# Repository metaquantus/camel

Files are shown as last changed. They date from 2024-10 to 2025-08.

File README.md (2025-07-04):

# Camel I2C Dual HX712 Weigh Scales Board

Camel is a board with Dual HX712 Weigh Scales ADCs controlled by a low power STM32L010F4 or STM32L031F6 MCU providing an I2C slave interface.
Power is provided by an I2C Adafruit STEMMA compatible 4-pin JST PH (2mm pitch) connector. This board will work 
with power from 3.3V to 5V, but it's better if VCC > 4V. 

It was intended to support the integrated scales mod for the Gaggia Classic Pro espresso machine provided by the Gaggiuino project. But instead of the main MCU driving the HX712s directly, sensor reading and decoding is offloaded to this board's MCU and a simple I2C interface is used instead to connect to the host MCU. This reduces the number of wires required, frees some pins in the host MCU and saves some clock cycles.

STEMMA Pinouts:
```
1 Green for SCL
2 White for SDA
3 Red for VCC+
4 Black for GND
```

The MCU drives the 2 HX712 ADCs, reads and decodes the conversions and provides the raw data to the host via I2C. 
The HX712s allow programmatic configuration of the sampling rate (10Hz or 40Hz), the amplifier's gain
factor (128 or 256) and whether to put the HX712s into power down mode consuming less than 1uA.
The device can also store configuration and calibration points in the MCU's EEPROM. Up to 4 calibration points 
are supported. 
The host is in charge of providing additional functions like scaling to weight units, tare and calibration.
It may be possible to offload scaling to the MCU, if using STM32L031F6 as it has more memory.
I2C doesn't support slave initiated transfers so the host MCU must poll the device periodically to read the data.
There will be roughly one new sensor reading available of both load cells every 100ms if 10Hz sampling rate is used. 
The internal oscillator is used in both the HX712 ADCs and the MCU so sampling rates are not very precise.
Using the lower sampling rate has lower conversion noise. The HX712 is a 24-bit ADC and data is provided in 2's complement format.
Readings could be negative depending on how the load cell is mechanically setup, bending one way of the other.
For example, in some of the integrated scales mod assembles, one cell gives positive values and 
the other negative. To get the total weight reading, the absolute values of both cells should be added.

According to STM32CubeIDE, the MCU should consume about 5mA and the HX712s about 1mA each. 

If using only one of the HX712s, it's possible power down the other, saving 1mA. This can be configured from
the host.

Programming is done via a Serial Wire Debug (SWD) connector. Both a Tag-Connect TC2030-NL and a 4-pin 2.54mm pitch header are provided for SWD.

A USART connector is provided but the STM32L010F4 has only 16Kb flash/2Kb RAM and adding code support exceeds code size limit. Some reporting
was tried but code size was very tight. This was intended for monitor and debugging during development, so it's not essential. Maybe with the
STM32L031F6 with 32KB flash/8KB RAM more monitoring and functions like standalone calibration can be added.

ESD protection diodes were added to the interface connectors.

2.54mm pitch header THT pads are used for the load cell connectors, but normally the load cells wires should be soldered directly to the pads instead of using headers or other connector.

## PCB Notes

The variable FAB\_ON\_PLACEHOLDER should be set to JLCJLCJLCJLC, WayWayWay or whatever string is specified by the Fab to position the order number.
Or removed altogether if so desired. Sometimes a fee is incurred if removed.

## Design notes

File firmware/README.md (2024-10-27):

# Camel Weigh Scales Board Firmware

This MCU only has 16KB flash storage and 2KB RAM, so we're pretty tight.
In fact it doesn't fit in Debug mode.
In Release mode it takes about 10KB.
No space for USART code, maybe if we don't use the HAL libraries,
we can squeze some basic code for the USART, though not needed if the main
functions of reading the HX711 and providing the I2C driver are supported.

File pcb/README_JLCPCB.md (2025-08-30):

# JLCPCB Procedure

## Gerbers

### Layers:
 * F.Cu
 * B.Cu
 * F.Paste
 * B.Paste
 * F.Silkscreen
 * B.Silkscreen
 * F.Mask
 * B.Mask
 * Edge.Cuts - (contain the board outline/cutouts.)
 * In1.Cu, In2.Cu … - (needed for 4/6 layer designs.)
 
### Options
 * Select Plot reference designators, otherwise designators will not appear on silkscreen layers;
 * Select Plot footprint text;
 * Select Check zone fills before plotting;
 * Select Tent vias;
 * Select Use Protel filename extensions, this is recommended as JLCPCB prefers Protel filename extensions;
 * Select Subtract soldermask from silkscreen, this ensures no silkscreen on pads;

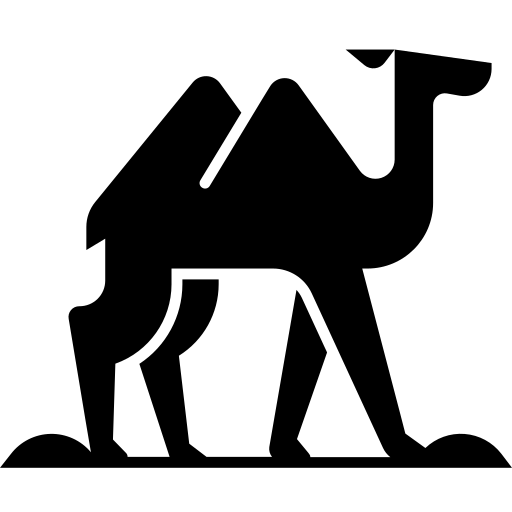
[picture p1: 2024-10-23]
other/camel1.png

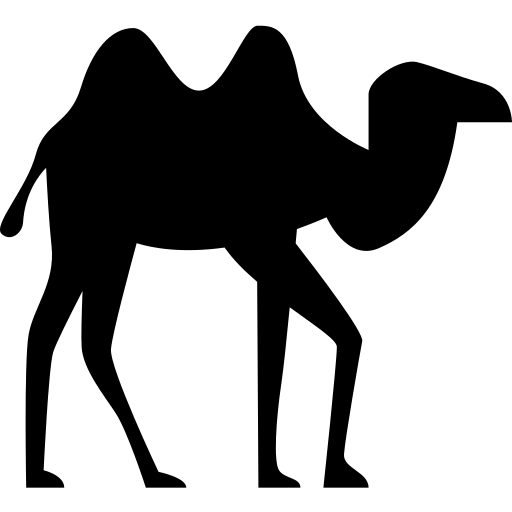
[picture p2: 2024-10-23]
other/camel2.png

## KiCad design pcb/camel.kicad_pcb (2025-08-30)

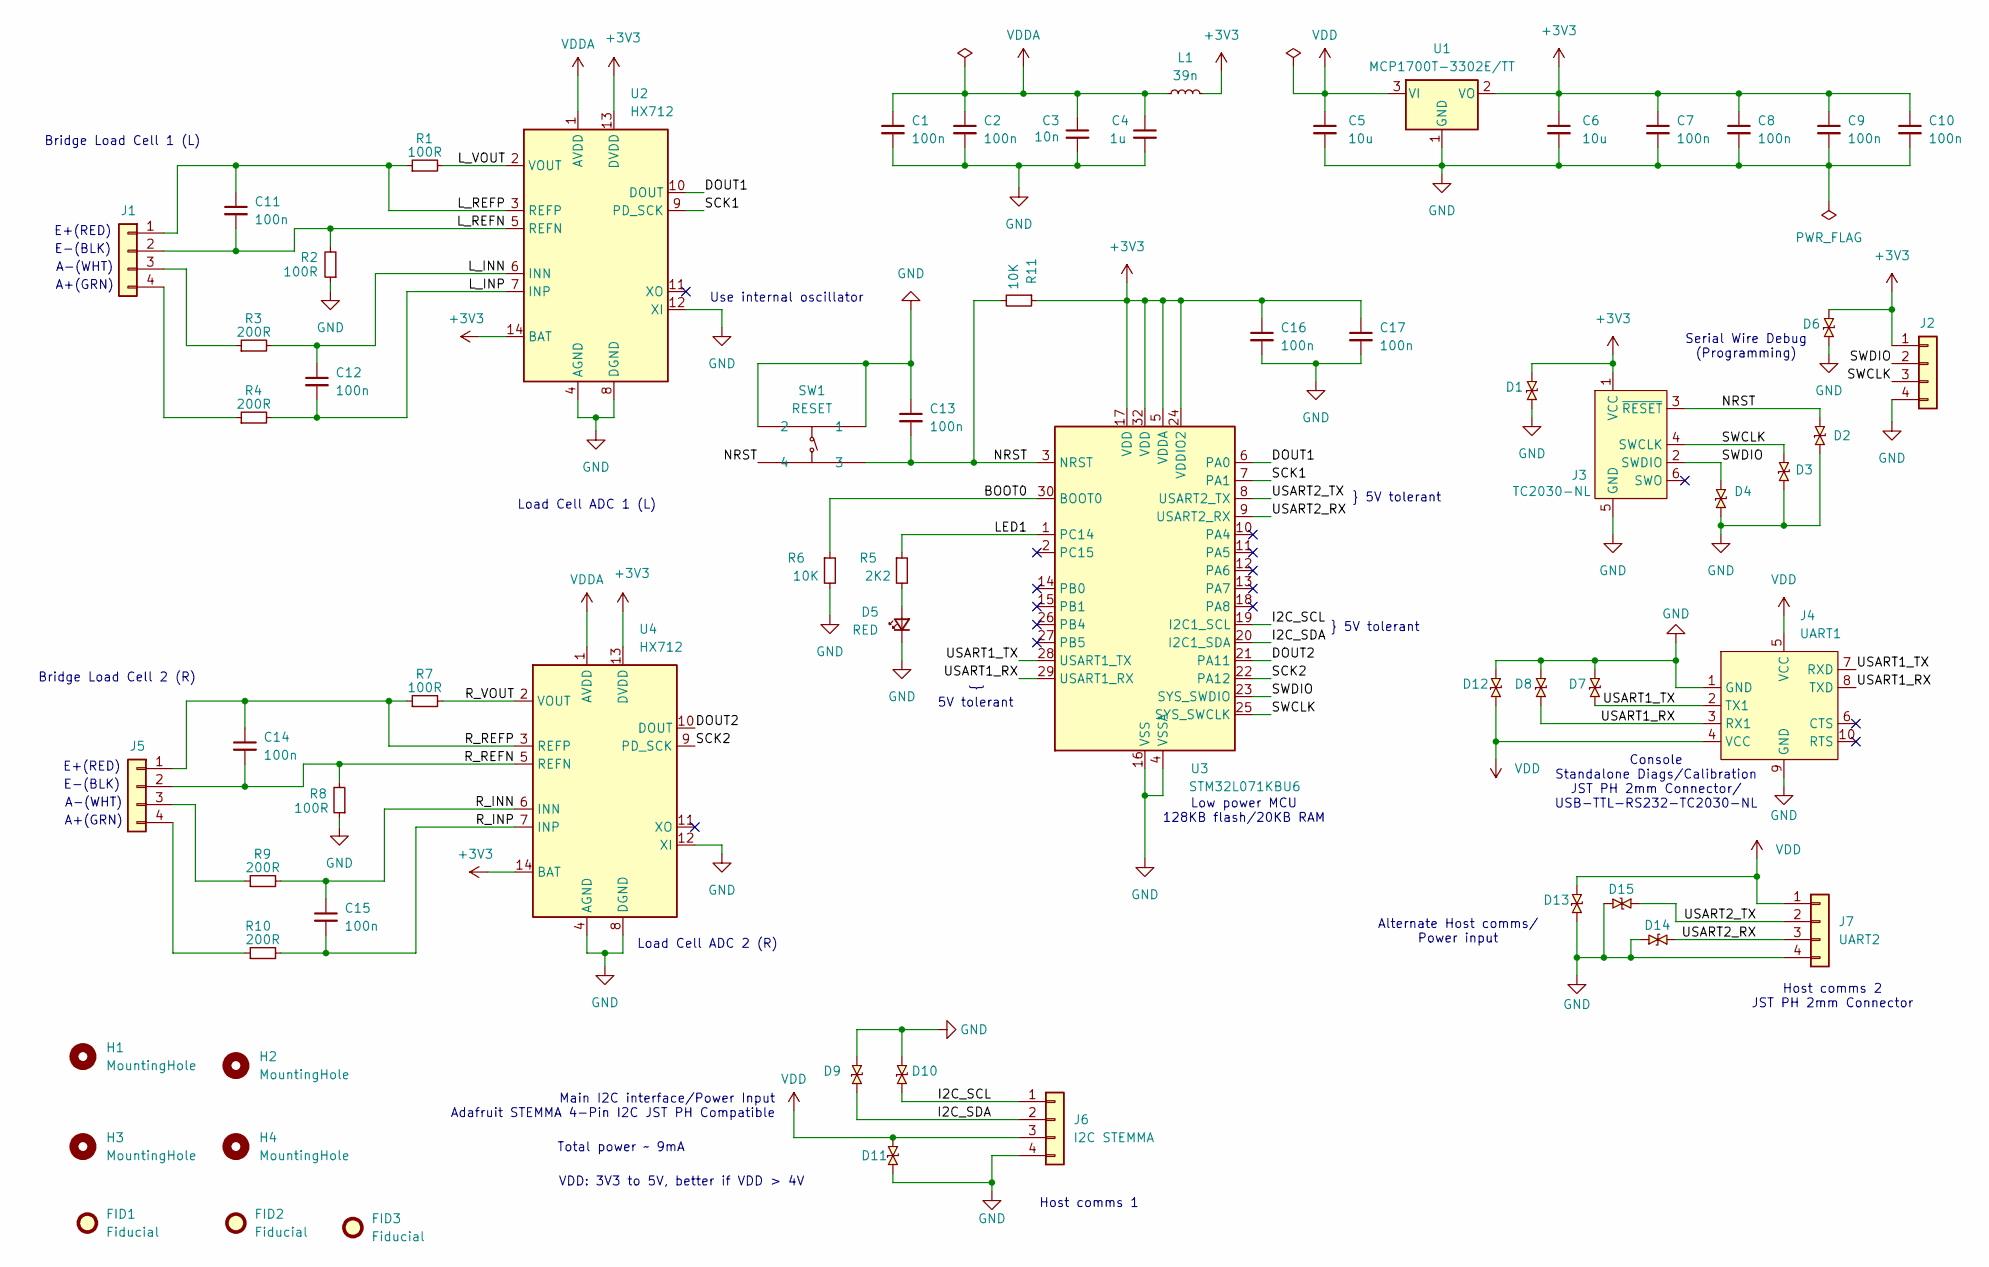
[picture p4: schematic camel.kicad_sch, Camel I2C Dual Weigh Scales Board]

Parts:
C1, C2, C7, C8, C9, C10, C11, C12, C13, C14, C15, C16, C17: 100n; C_0402_1005Metric; LCSC C1525
C3: 10n; C_0402_1005Metric; LCSC C15195
C4: 1u; C_0402_1005Metric; LCSC C29266
C5, C6: 10u; C_0603_1608Metric; LCSC C96446
D1, D2, D3, D4, D6, D7, D8, D9, D10, D11, D12, D13, D14, D15: RCLAMP0521P-N; X1-DFN1006-2_L1.0-W0.6-BI; LCSC C316043
D5: RED; LED_0603_1608Metric; LCSC C2286
FID1, FID2, FID3: Fiducial; Fiducial_0.5mm_Mask1mm
H1, H2, H3, H4: MountingHole; MountingHole_3.2mm_M3
J1, J2, J5: Conn_01x04; Pad_1x04_P2.54mm
J3: TC2030-NL; Tag-Connect_TC2030-IDC-NL_2x03_P1.27mm_Vertical
J4: UART1; JST_PH_S4B-PH-K_1x04_P2.00mm_Horizontal_TC-2030-IDC-NL_2x03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
J6: I2C STEMMA; JST_PH_S4B-PH-K_1x04_P2.00mm_Horizontal; LCSC C265452
J7: UART2; JST_PH_S4B-PH-K_1x04_P2.00mm_Horizontal
L1: 39n; L_1008_2520Metric; LCSC C346422
R1, R2, R7, R8: 100R; R_0402_1005Metric; LCSC C328416
R3, R4, R9, R10: 200R; R_0402_1005Metric; LCSC C413070
R5: 2K2; R_0402_1005Metric; LCSC C25879
R6, R11: 10K; R_0402_1005Metric; LCSC C317926
SW1: RESET; SW-SMD_4P-L3.0-W2.6-P1.80-LS3.5; LCSC Part C390663
U1: MCP1700T-3302E/TT; SOT-23; LCSC C39051
U2, U4: HX712; SOIC-14_3.9x8.7mm_P1.27mm; LCSC C118237
U3: STM32L071KBU6; QFN-32-1EP_5x5mm_P0.5mm_EP3.45x3.45mm; LCSC C911078

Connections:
+3V3: C6.1, C7.1, C8.1, C9.1, C10.1, C16.1, C17.1, D1.1, D6.1, J2.1, J3.1 (VCC), L1.2, R11.1, U1.2 (VO), U2.13 (DVDD), U2.14 (BAT), U3.5 (VDDA), U3.17 (VDD), U3.24 (VDDIO2), U3.32 (VDD), U4.13 (DVDD), U4.14 (BAT)
/BOOT0: R6.1, U3.30 (BOOT0)
/DOUT1: U2.10 (DOUT), U3.6 (PA0)
/DOUT2: U3.21 (PA11), U4.10 (DOUT)
/I2C_SCL: D10.2, J6.1, U3.19 (I2C1_SCL)
/I2C_SDA: D9.2, J6.2, U3.20 (I2C1_SDA)
/LED1: R5.1, U3.1 (PC14)
/L_INN: C12.1, R3.2, U2.6 (INN)
/L_INP: C12.2, R4.2, U2.7 (INP)
/L_REFN: C11.2, J1.2, R2.2, U2.5 (REFN)
/L_REFP: C11.1, J1.1, R1.1, U2.3 (REFP)
/L_VOUT: R1.2, U2.2 (VOUT)
/NRST: C13.2, D2.1, J3.3 (~RESET), R11.2, SW1.3, SW1.4, U3.3 (NRST)
/R_INN: C15.1, R9.2, U4.6 (INN)
/R_INP: C15.2, R10.2, U4.7 (INP)
/R_REFN: C14.2, J5.2, R8.2, U4.5 (REFN)
/R_REFP: C14.1, J5.1, R7.1, U4.3 (REFP)
/R_VOUT: R7.2, U4.2 (VOUT)
/SCK1: U2.9 (PD_SCK), U3.7 (PA1)
/SCK2: U3.22 (PA12), U4.9 (PD_SCK)
/SWCLK: D3.1, J2.3, J3.4 (SWCLK), U3.25 (SYS_SWCLK)
/SWDIO: D4.1, J2.2, J3.2 (SWDIO), U3.23 (SYS_SWDIO)
/USART1_RX: D8.2, J4.3 (RX1), J4.8 (TXD), U3.29 (USART1_RX)
/USART1_TX: D7.2, J4.2 (TX1), J4.7 (RXD), U3.28 (USART1_TX)
/USART2_RX: D14.2, J7.3, U3.9 (USART2_RX)
/USART2_TX: D15.2, J7.2, U3.8 (USART2_TX)
GND: C1.2, C2.2, C3.2, C4.2, C5.2, C6.2, C7.2, C8.2, C9.2, C10.2, C13.1, C16.2, C17.2, D1.2, D2.2, D3.2, D4.2, D5.1 (K), D6.2, D7.1, D8.1, D9.1, D10.1, D11.2, D12.1, D13.2, D14.1, D15.1, J2.4, J3.5 (GND), J4.1 (GND), J4.9 (GND), J6.4, J7.4, R2.1, R6.2, R8.1, SW1.1, SW1.2, U1.1 (GND), U2.4 (AGND), U2.8 (DGND), U2.12 (XI), U3.4 (VSSA), U3.16 (VSS), U3.31 (VSS), U3.33 (VSS), U4.4 (AGND), U4.8 (DGND), U4.12 (XI)
unnamed: D5.2 (A), R5.2
unnamed: J1.3, R3.1
unnamed: J1.4, R4.1
unnamed: J5.3, R9.1
unnamed: J5.4, R10.1
VDD: C5.1, D11.1, D12.2, D13.1, J4.4 (VCC), J4.5 (VCC), J6.3, J7.1, U1.3 (VI)
VDDA: C1.1, C2.1, C3.1, C4.1, L1.1, U2.1 (AVDD), U4.1 (AVDD)

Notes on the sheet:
A-(WHT)
Bridge Load Cell 2 (R)
5V tolerant
Alternate Host comms/ Power input
Load Cell ADC 2 (R)
Host comms 2 JST PH 2mm Connector
Host comms 1
VDD: 3V3 to 5V, better if VDD > 4V
Console Standalone Diags/Calibration JST PH 2mm Connector/ USB-TTL-RS232-TC2030-NL
E+(RED)
Main I2C interface/Power Input Adafruit STEMMA 4-Pin I2C JST PH Compatible
Total power ~ 9mA
A+(GRN)
Low power MCU 128KB flash/20KB RAM
E-(BLK)
Load Cell ADC 1 (L)
Serial Wire Debug (Programming)
} 5V tolerant
Use internal oscillator
Bridge Load Cell 1 (L)

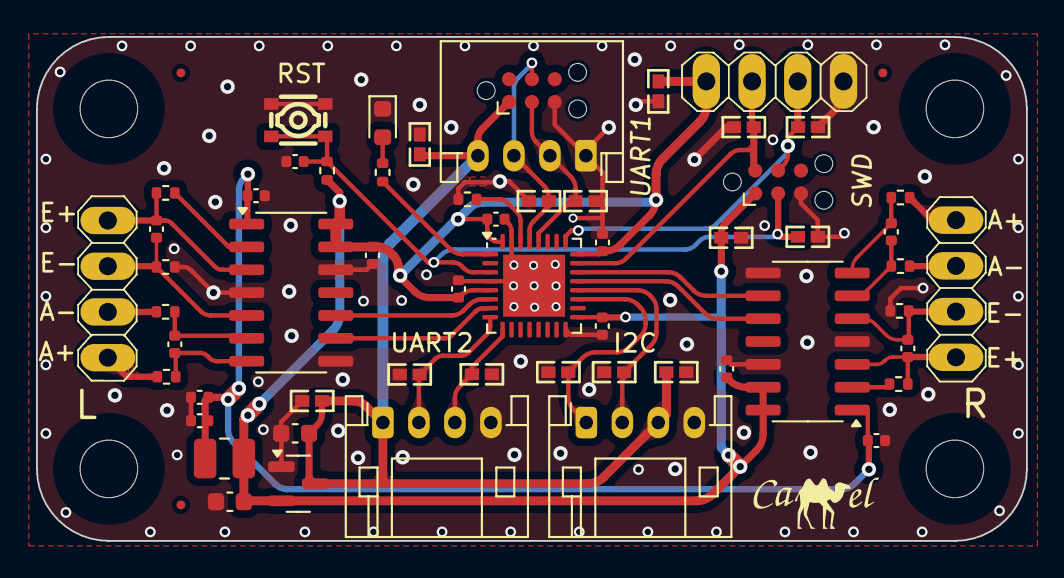
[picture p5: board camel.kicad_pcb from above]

Board: 4 copper layers, 55.0 x 28.0 mm, 65 parts (1 on the bottom side), 34 nets.

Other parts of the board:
G3: LOGO; camel_logo_7
QR1: QR; camel_qrcode_5x5

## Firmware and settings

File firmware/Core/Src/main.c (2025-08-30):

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
/* Includes ------------------------------------------------------------------*/
#include "main.h"
#include "cmsis_os.h"

CRC_HandleTypeDef hcrc;

I2C_HandleTypeDef hi2c1;

UART_HandleTypeDef huart1;
UART_HandleTypeDef huart2;
DMA_HandleTypeDef hdma_usart1_tx;
DMA_HandleTypeDef hdma_usart1_rx;
DMA_HandleTypeDef hdma_usart2_tx;
DMA_HandleTypeDef hdma_usart2_rx;

/* Definitions for defaultTask */
osThreadId_t defaultTaskHandle;
const osThreadAttr_t defaultTask_attributes = {
  .name = "defaultTask",
  .stack_size = 128 * 4,
  .priority = (osPriority_t) osPriorityNormal,
};
/* Definitions for consoleTask */
osThreadId_t consoleTaskHandle;
const osThreadAttr_t consoleTask_attributes = {
  .name = "consoleTask",
  .stack_size = 320 * 4,
  .priority = (osPriority_t) osPriorityLow7,
};
/* Definitions for hostCommTask */
osThreadId_t hostCommTaskHandle;
const osThreadAttr_t hostCommTask_attributes = {
  .name = "hostCommTask",
  .stack_size = 128 * 4,
  .priority = (osPriority_t) osPriorityBelowNormal,
};
/* Definitions for indicatorTask */
osThreadId_t indicatorTaskHandle;
const osThreadAttr_t indicatorTask_attributes = {
  .name = "indicatorTask",
  .stack_size = 192 * 4,
  .priority = (osPriority_t) osPriorityLow,
};
void SystemClock_Config(void);
static void MX_GPIO_Init(void);
static void MX_DMA_Init(void);
static void MX_I2C1_Init(void);
static void MX_USART1_UART_Init(void);
static void MX_USART2_UART_Init(void);
static void MX_CRC_Init(void);
void StartDefaultTask(void *argument);
extern void StartConsoleTask(void *argument);
extern void StartCommTask(void *argument);
extern void StartIndicatorTask(void *argument);

/**
  * @brief  The application entry point.
  * @retval int
  */
int main(void)
{

  /* MCU Configuration--------------------------------------------------------*/

  /* Reset of all peripherals, Initializes the Flash interface and the Systick. */
  HAL_Init();

  /* Configure the system clock */
  SystemClock_Config();

  /* Initialize all configured peripherals */
  MX_GPIO_Init();
  MX_DMA_Init();
  MX_I2C1_Init();
  MX_USART1_UART_Init();
  MX_USART2_UART_Init();
  MX_CRC_Init();
  /* Init scheduler */
  osKernelInitialize();

  /* USER CODE BEGIN RTOS_MUTEX */
  /* add mutexes, ... */
  /* USER CODE END RTOS_MUTEX */

  /* USER CODE BEGIN RTOS_SEMAPHORES */
  /* add semaphores, ... */
  /* USER CODE END RTOS_SEMAPHORES */

  /* USER CODE BEGIN RTOS_TIMERS */
  /* start timers, add new ones, ... */
  /* USER CODE END RTOS_TIMERS */

  /* USER CODE BEGIN RTOS_QUEUES */
  /* add queues, ... */
  /* USER CODE END RTOS_QUEUES */

  /* Create the thread(s) */
  /* creation of defaultTask */
  defaultTaskHandle = osThreadNew(StartDefaultTask, NULL, &defaultTask_attributes);

  /* creation of consoleTask */
  consoleTaskHandle = osThreadNew(StartConsoleTask, NULL, &consoleTask_attributes);

  /* creation of hostCommTask */
  hostCommTaskHandle = osThreadNew(StartCommTask, NULL, &hostCommTask_attributes);

  /* creation of indicatorTask */
  indicatorTaskHandle = osThreadNew(StartIndicatorTask, NULL, &indicatorTask_attributes);

  /* USER CODE BEGIN RTOS_THREADS */
  /* add threads, ... */
  /* USER CODE END RTOS_THREADS */

  /* USER CODE BEGIN RTOS_EVENTS */
  /* add events, ... */
  /* USER CODE END RTOS_EVENTS */

  /* Start scheduler */
  osKernelStart();

  /* We should never get here as control is now taken by the scheduler */

  /* Infinite loop */
  /* USER CODE BEGIN WHILE */
  while (1)
  {
    /* USER CODE END WHILE */

    /* USER CODE BEGIN 3 */
    HAL_GPIO_TogglePin(LED1_GPIO_Port, LED1_Pin);
    HAL_Delay(400);
    HAL_GPIO_TogglePin(LED1_GPIO_Port, LED1_Pin);
    HAL_Delay(400);
  }
  /* USER CODE END 3 */
}

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
/* USER CODE BEGIN Header_StartDefaultTask */
/**
  * @brief  Function implementing the defaultTask thread.
  * @param  argument: Not used
  * @retval None
  */
/* USER CODE END Header_StartDefaultTask */
__weak void StartDefaultTask(void *argument)
{
  /* USER CODE BEGIN 5 */
  /* Infinite loop */
  for(;;)
  {
    osDelay(1);
  }
  /* USER CODE END 5 */
}

/**
  * @brief  Period elapsed callback in non blocking mode
  * @note   This function is called  when TIM22 interrupt took place, inside
  * HAL_TIM_IRQHandler(). It makes a direct call to HAL_IncTick() to increment
  * a global variable "uwTick" used as application time base.
  * @param  htim : TIM handle
  * @retval None
  */
void HAL_TIM_PeriodElapsedCallback(TIM_HandleTypeDef *htim)
{
  if (htim->Instance == TIM22)
  {
    HAL_IncTick();
  }
}

/**
  * @brief  This function is executed in case of error occurrence.
  * @retval None
  */
void Error_Handler(void)
{
  /* USER CODE BEGIN Error_Handler_Debug */
  /* User can add his own implementation to report the HAL error return state */
  __disable_irq();
  while (1)
  {
  }
  /* USER CODE END Error_Handler_Debug */
}
#ifdef USE_FULL_ASSERT
/**
  * @brief  Reports the name of the source file and the source line number
  *         where the assert_param error has occurred.
  * @param  file: pointer to the source file name
  * @param  line: assert_param error line source number
  * @retval None
  */
void assert_failed(uint8_t *file, uint32_t line)
{
  /* USER CODE BEGIN 6 */
  /* User can add his own implementation to report the file name and line number,
     ex: printf("Wrong parameters value: file %s on line %d\r\n", file, line) */
  /* USER CODE END 6 */
}
#endif /* USE_FULL_ASSERT */

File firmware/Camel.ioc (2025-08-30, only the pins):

Mcu.UserName=STM32L071KBUx
PA0.GPIO_Label=DOUT1
PA0.Signal=GPXTI0
PA1.GPIO_Label=SCK1
PA1.Signal=GPIO_Output
PA10.Signal=I2C1_SDA
PA11.GPIO_Label=DOUT2
PA11.Signal=GPXTI11
PA12.GPIO_Label=SCK2
PA12.Signal=GPIO_Output
PA13.Signal=SYS_SWDIO
PA14.Signal=SYS_SWCLK
PA2.Signal=USART2_TX
PA3.Signal=USART2_RX
PA9.Signal=I2C1_SCL
PB6.Signal=USART1_TX
PB7.Signal=USART1_RX
PC14-OSC32_IN.GPIO_Label=LED1
PC14-OSC32_IN.Signal=GPIO_Output

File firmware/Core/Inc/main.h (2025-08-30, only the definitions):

#define CAMEL_ADDRESS 0x75
#define LED1_Pin GPIO_PIN_14
#define LED1_GPIO_Port GPIOC
#define DOUT1_Pin GPIO_PIN_0
#define DOUT1_GPIO_Port GPIOA
#define DOUT1_EXTI_IRQn EXTI0_1_IRQn
#define SCK1_Pin GPIO_PIN_1
#define SCK1_GPIO_Port GPIOA
#define DOUT2_Pin GPIO_PIN_11
#define DOUT2_GPIO_Port GPIOA
#define DOUT2_EXTI_IRQn EXTI4_15_IRQn
#define SCK2_Pin GPIO_PIN_12
#define SCK2_GPIO_Port GPIOA

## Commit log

2024-10-12 Initial import
    [camel.kicad_pcb, camel.kicad_sch, camel_bom.ods]
2024-10-23 first pass
    [camel.kicad_pcb, camel.kicad_sch, camel_bom.ods]
2024-11-08 added extra SWD connector in addition to TagConnect
    [camel.kicad_pcb, camel.kicad_sch, camel_bom.ods]
2024-11-10 replaced with hx712, updated schematics and pcb
    [camel.kicad_pcb, camel.kicad_sch, camel_bom.ods]
2024-11-15 PCB updates, teardrops and trace cleanup
    [camel.kicad_pcb, camel.kicad_sch, camel_bom.ods]
2024-11-23 PCB refactoring, BOM updates, firmware added EEPROM storage of configuration
    [camel.kicad_pcb, camel.kicad_sch, camel_bom.ods]
2024-11-28 PCBway additions
    [camel.kicad_pcb]
2025-07-04 updated STM32CubeMX version, updating to STM32L031F6
    [camel.kicad_pcb, camel.kicad_sch, camel_bom.ods]
2025-07-07 version 3.0 update MCU and VDD on USART connector, prepare for JLCPCB
    [camel.kicad_pcb, camel.kicad_sch]
2025-07-09 device tare and calibration functions
2025-07-24 Starting to update MCU
    [camel_bom.ods]
2025-07-24 updated to PCB ver 3.0
2025-08-30 Update to STM32L071 and FreeRTOS, first stage
    [Camel.cfg, camel.kicad_pcb, camel.kicad_sch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]

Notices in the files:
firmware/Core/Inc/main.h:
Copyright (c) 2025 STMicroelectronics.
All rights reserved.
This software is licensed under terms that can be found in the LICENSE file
